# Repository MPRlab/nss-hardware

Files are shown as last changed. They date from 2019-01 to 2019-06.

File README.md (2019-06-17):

# Nucleo Solenoid Shield - Hardware

This repository contains the KiCad files for the Nucleo Solenoid Shield.

Each version of the shield (A/B/C) can drive 25 solenoids from different sets of IO pins. The exact pin names can be found [here](https://docs.google.com/spreadsheets/d/1F1l6_GBWTKrIMixAlwO8Ikh-0bkGv4sUIIGNAyeHcug/edit?usp=sharing). 

The board is powered from a 4-pin ATX connector. The two contacts closest to the latch are the supply voltage and the two pins away from the latch are ground.

Next to the main power input is a secondary input for 5V to the Nucleo. The pin closest to the ATX connectore is 5V in, the middle pin is ground, and the third pin is connected to the solenoid supply voltage.

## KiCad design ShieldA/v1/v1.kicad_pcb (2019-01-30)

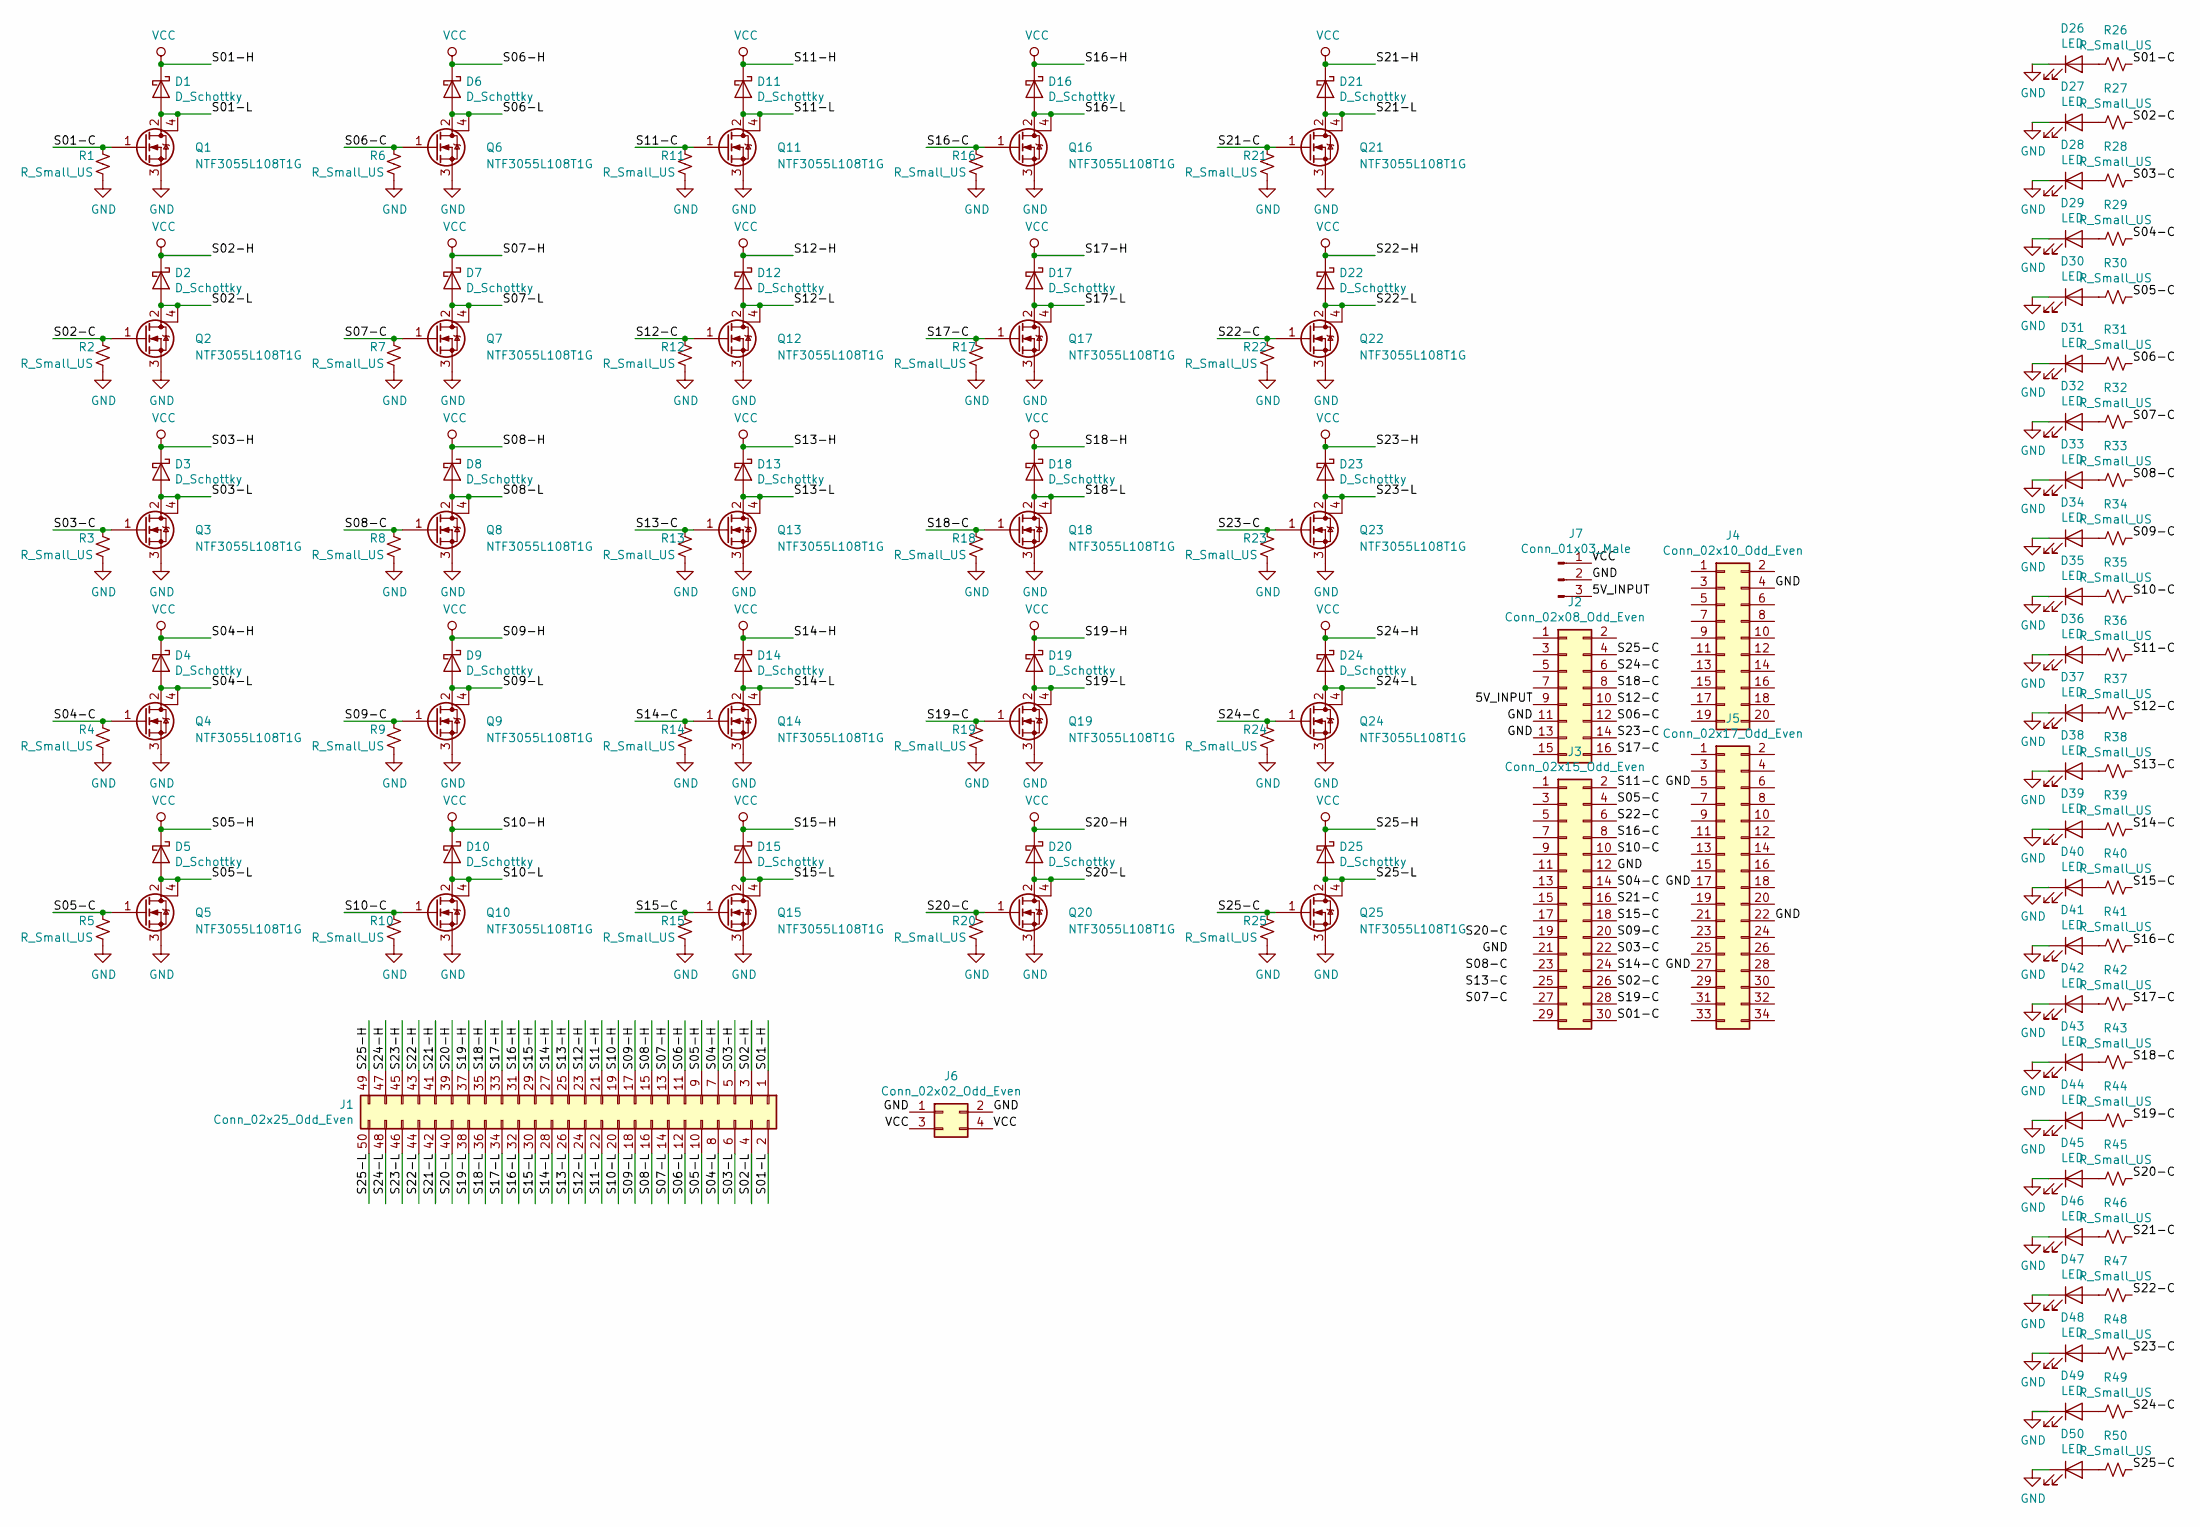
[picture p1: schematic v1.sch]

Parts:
D1, D2, D3, D4, D5, D6, D7, D8, D9, D10, D11, D12, D13, D14, D15, D16, D17, D18, D19, D20, D21, D22, D23, D24, D25: D_Schottky; D_SOD-123F
D26, D27, D28, D29, D30, D31, D32, D33, D34, D35, D36, D37, D38, D39, D40, D41, D42, D43, D44, D45, D46, D47, D48, D49, D50: LED; LED_0805_2012Metric_Pad1.15x1.40mm_HandSolder
J1: Conn_02x25_Odd_Even; PinHeader_2x25_P2.54mm_Horizontal
J2: Conn_02x08_Odd_Even; PinHeader_2x08_P2.54mm_Vertical
J3: Conn_02x15_Odd_Even; PinHeader_2x15_P2.54mm_Vertical
J4: Conn_02x10_Odd_Even; PinHeader_2x10_P2.54mm_Vertical
J5: Conn_02x17_Odd_Even; PinHeader_2x17_P2.54mm_Vertical
J6: Conn_02x02_Odd_Even; Molex_Mini-Fit_Jr_5569-04A2_2x02_P4.20mm_Horizontal
J7: Conn_01x03_Male; PinHeader_1x03_P2.54mm_Horizontal
Q1, Q2, Q3, Q4, Q5, Q6, Q7, Q8, Q9, Q10, Q11, Q12, Q13, Q14, Q15, Q16, Q17, Q18, Q19, Q20, Q21, Q22, Q23, Q24, Q25: NTF3055L108T1G; SOT-223
R1, R2, R3, R4, R5, R6, R7, R8, R9, R10, R11, R12, R13, R14, R15, R16, R17, R18, R19, R20, R21, R22, R23, R24, R25, R26, R27, R28, R29, R30, R31, R32, R33, R34, R35, R36, R37, R38, R39, R40, R41, R42, R43, R44, R45, R46, R47, R48, R49, R50: R_Small_US; R_0805_2012Metric_Pad1.15x1.40mm_HandSolder

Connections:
/5V_INPUT: J2.9, J7.3
/S01-C: J3.30, Q1.1 (G), R1.1, R26.1
/S01-L: D1.2 (A), J1.2, Q1.2 (D), Q1.4 (D)
/S02-C: J3.26, Q2.1 (G), R2.1, R27.1
/S02-L: D2.2 (A), J1.4, Q2.2 (D), Q2.4 (D)
/S03-C: J3.22, Q3.1 (G), R3.1, R28.1
/S03-L: D3.2 (A), J1.6, Q3.2 (D), Q3.4 (D)
/S04-C: J3.14, Q4.1 (G), R4.1, R29.1
/S04-L: D4.2 (A), J1.8, Q4.2 (D), Q4.4 (D)
/S05-C: J3.4, Q5.1 (G), R5.1, R30.1
/S05-L: D5.2 (A), J1.10, Q5.2 (D), Q5.4 (D)
/S06-C: J2.12, Q6.1 (G), R6.1, R31.1
/S06-L: D6.2 (A), J1.12, Q6.2 (D), Q6.4 (D)
/S07-C: Q7.1 (G), R7.1, R32.1
/S07-L: D7.2 (A), J1.14, Q7.2 (D), Q7.4 (D)
/S08-C: Q8.1 (G), R8.1, R33.1
/S08-L: D8.2 (A), J1.16, Q8.2 (D), Q8.4 (D)
/S09-C: J3.20, Q9.1 (G), R9.1, R34.1
/S09-L: D9.2 (A), J1.18, Q9.2 (D), Q9.4 (D)
/S10-C: J3.10, Q10.1 (G), R10.1, R35.1
/S10-L: D10.2 (A), J1.20, Q10.2 (D), Q10.4 (D)
/S11-C: J3.2, Q11.1 (G), R11.1, R36.1
/S11-L: D11.2 (A), J1.22, Q11.2 (D), Q11.4 (D)
/S12-C: J2.10, Q12.1 (G), R12.1, R37.1
/S12-L: D12.2 (A), J1.24, Q12.2 (D), Q12.4 (D)
/S13-C: Q13.1 (G), R13.1, R38.1
/S13-L: D13.2 (A), J1.26, Q13.2 (D), Q13.4 (D)
/S14-C: J3.24, Q14.1 (G), R14.1, R39.1
/S14-L: D14.2 (A), J1.28, Q14.2 (D), Q14.4 (D)
/S15-C: J3.18, Q15.1 (G), R15.1, R40.1
/S15-L: D15.2 (A), J1.30, Q15.2 (D), Q15.4 (D)
/S16-C: J3.8, Q16.1 (G), R16.1, R41.1
/S16-L: D16.2 (A), J1.32, Q16.2 (D), Q16.4 (D)
/S17-C: J2.16, Q17.1 (G), R17.1, R42.1
/S17-L: D17.2 (A), J1.34, Q17.2 (D), Q17.4 (D)
/S18-C: J2.8, Q18.1 (G), R18.1, R43.1
/S18-L: D18.2 (A), J1.36, Q18.2 (D), Q18.4 (D)
/S19-C: J3.28, Q19.1 (G), R19.1, R44.1
/S19-L: D19.2 (A), J1.38, Q19.2 (D), Q19.4 (D)
/S20-C: Q20.1 (G), R20.1, R45.1
/S20-L: D20.2 (A), J1.40, Q20.2 (D), Q20.4 (D)
/S21-C: J3.16, Q21.1 (G), R21.1, R46.1
/S21-L: D21.2 (A), J1.42, Q21.2 (D), Q21.4 (D)
/S22-C: J3.6, Q22.1 (G), R22.1, R47.1
/S22-L: D22.2 (A), J1.44, Q22.2 (D), Q22.4 (D)
/S23-C: J2.14, Q23.1 (G), R23.1, R48.1
/S23-L: D23.2 (A), J1.46, Q23.2 (D), Q23.4 (D)
/S24-C: J2.6, Q24.1 (G), R24.1, R49.1
/S24-L: D24.2 (A), J1.48, Q24.2 (D), Q24.4 (D)
/S25-C: J2.4, Q25.1 (G), R25.1, R50.1
/S25-L: D25.2 (A), J1.50, Q25.2 (D), Q25.4 (D)
GND: D26.1 (K), D27.1 (K), D28.1 (K), D29.1 (K), D30.1 (K), D31.1 (K), D32.1 (K), D33.1 (K), D34.1 (K), D35.1 (K), D36.1 (K), D37.1 (K), D38.1 (K), D39.1 (K), D40.1 (K), D41.1 (K), D42.1 (K), D43.1 (K), D44.1 (K), D45.1 (K), D46.1 (K), D47.1 (K), D48.1 (K), D49.1 (K), D50.1 (K), J2.11, J2.13, J3.12, J4.4, J5.5, J5.17, J5.22, J5.27, J6.1, J6.2, J7.2, Q1.3 (S), Q2.3 (S), Q3.3 (S), Q4.3 (S), Q5.3 (S), Q6.3 (S), Q7.3 (S), Q8.3 (S), Q9.3 (S), Q10.3 (S), Q11.3 (S), Q12.3 (S), Q13.3 (S), Q14.3 (S), Q15.3 (S), Q16.3 (S), Q17.3 (S), Q18.3 (S), Q19.3 (S), Q20.3 (S), Q21.3 (S), Q22.3 (S), Q23.3 (S), Q24.3 (S), Q25.3 (S), R1.2, R2.2, R3.2, R4.2, R5.2, R6.2, R7.2, R8.2, R9.2, R10.2, R11.2, R12.2, R13.2, R14.2, R15.2, R16.2, R17.2, R18.2, R19.2, R20.2, R21.2, R22.2, R23.2, R24.2, R25.2
unnamed: D26.2 (A), R26.2
unnamed: D27.2 (A), R27.2
unnamed: D28.2 (A), R28.2
unnamed: D29.2 (A), R29.2
unnamed: D30.2 (A), R30.2
unnamed: D31.2 (A), R31.2
unnamed: D32.2 (A), R32.2
unnamed: D33.2 (A), R33.2
unnamed: D34.2 (A), R34.2
unnamed: D35.2 (A), R35.2
unnamed: D36.2 (A), R36.2
unnamed: D37.2 (A), R37.2
unnamed: D38.2 (A), R38.2
unnamed: D39.2 (A), R39.2
unnamed: D40.2 (A), R40.2
unnamed: D41.2 (A), R41.2
unnamed: D42.2 (A), R42.2
unnamed: D43.2 (A), R43.2
unnamed: D44.2 (A), R44.2
unnamed: D45.2 (A), R45.2
unnamed: D46.2 (A), R46.2
unnamed: D47.2 (A), R47.2
unnamed: D48.2 (A), R48.2
unnamed: D49.2 (A), R49.2
unnamed: D50.2 (A), R50.2
VCC: D1.1 (K), D2.1 (K), D3.1 (K), D4.1 (K), D5.1 (K), D6.1 (K), D7.1 (K), D8.1 (K), D9.1 (K), D10.1 (K), D11.1 (K), D12.1 (K), D13.1 (K), D14.1 (K), D15.1 (K), D16.1 (K), D17.1 (K), D18.1 (K), D19.1 (K), D20.1 (K), D21.1 (K), D22.1 (K), D23.1 (K), D24.1 (K), D25.1 (K), J1.1, J1.3, J1.5, J1.7, J1.9, J1.11, J1.13, J1.15, J1.17, J1.19, J1.21, J1.23, J1.25, J1.27, J1.29, J1.31, J1.33, J1.35, J1.37, J1.39, J1.41, J1.43, J1.45, J1.47, J1.49, J6.3, J6.4, J7.1

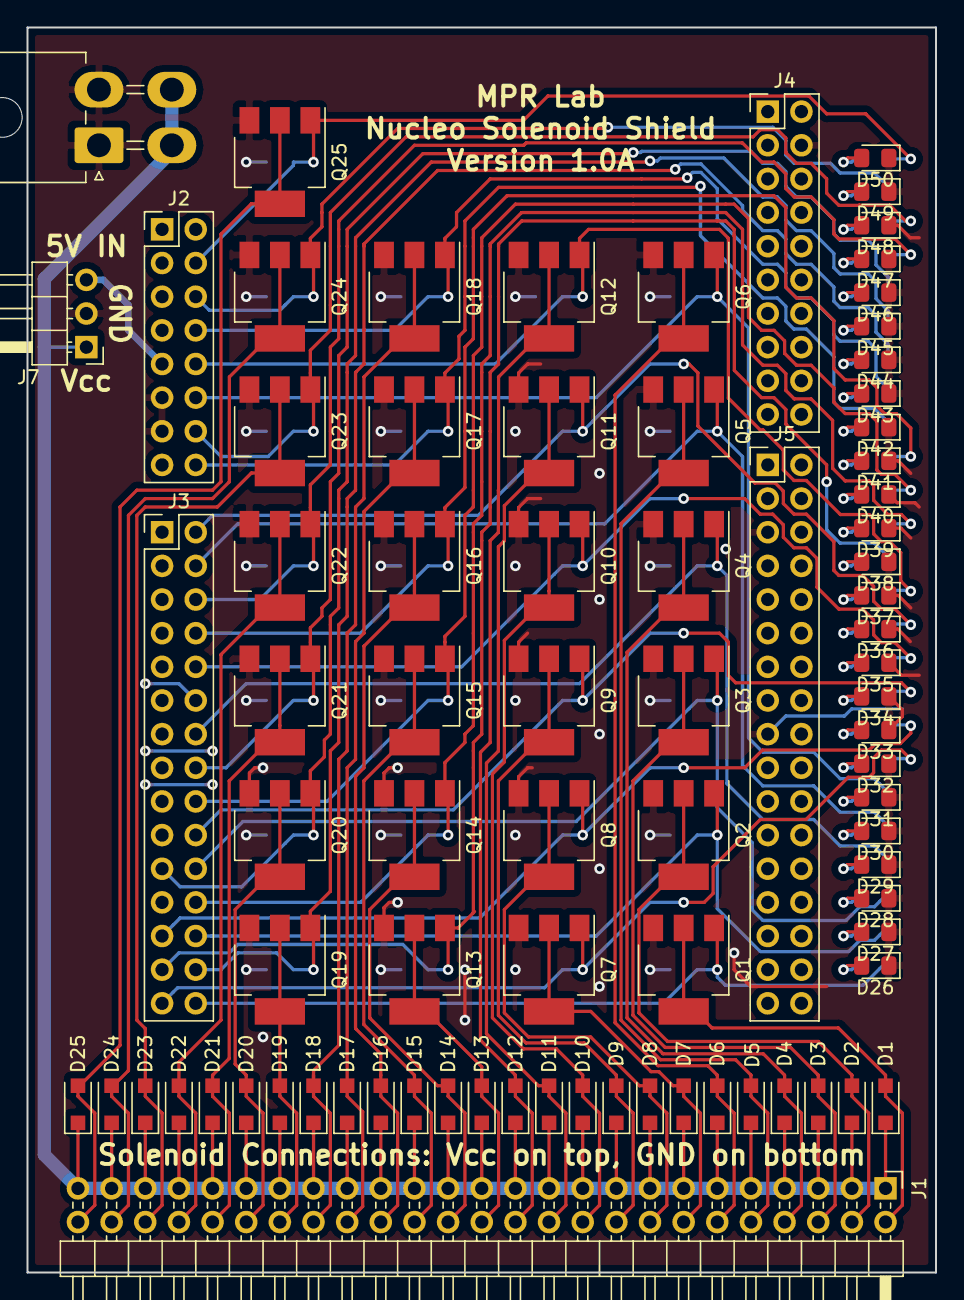
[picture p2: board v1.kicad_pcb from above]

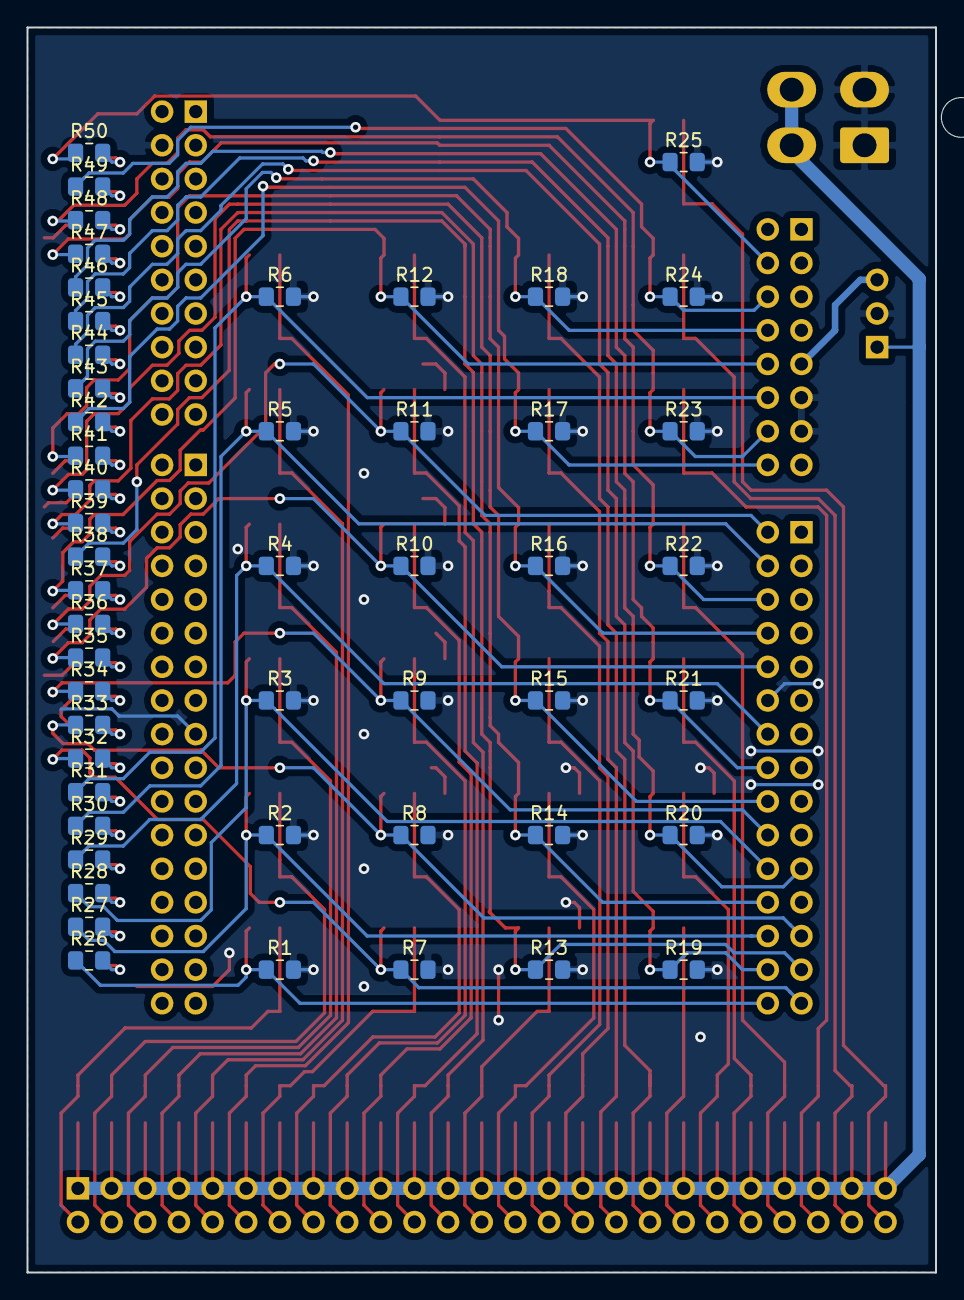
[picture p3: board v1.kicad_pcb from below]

Board: 2 copper layers, 68.6 x 94.0 mm, 132 parts (50 on the bottom side), 78 nets.
